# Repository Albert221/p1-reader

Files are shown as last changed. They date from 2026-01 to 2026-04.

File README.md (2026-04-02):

# P1 Reader

A simple device connecting a [Seeed ESP32-C3](https://wiki.seeedstudio.com/XIAO_ESP32C3_Getting_Started/) to a P1 port of the electricity meter. Based on ESPHome.

> [!NOTE]
> This project is dedicated to working with Polish STOEN operator, using GAMA 350 meter.

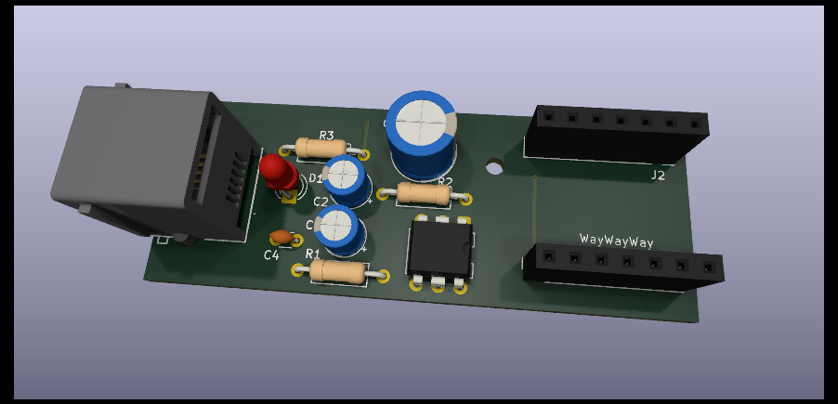
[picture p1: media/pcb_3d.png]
PCB 3D screenshot


## KiCAD

In `kicad/MJ3235-66-0` directory you should put a 3D model of the RJ12 connector that you can get from [here](https://www.tme.eu/pl/details/mj3235-66-0/zlacza-rj/gct/). I'm not sharing it as its license doesn't allow model file redistribution.

In PCB, there is 1K pull-up resistor between Data and 3V3 missing.

## Components

- [RJ12 connector](https://www.tme.eu/pl/details/mj3235-66-0/zlacza-rj/gct/)
- Electrolytic capacitors 100uF, 10uF, 1uF
- Ceramic capacitor 100nF
- Resistors 56Ω, 100Ω, 200Ω, 1kΩ
- Amber LED 3mm
- Optocoupler 4N35
- 2x 1x7 header socket (for connecting to ESP, chip facing down, USB to the edge of PCB)

## Sources

- https://forum.arturhome.pl/t/elgama-gama-350-i-port-p1/13722/21
- https://esphome.io/components/sensor/dsmr/
- https://www.netbeheernederland.nl/sites/default/files/2024-02/dsmr_5.0.2_p1_companion_standard.pdf ([Web Archive](https://web.archive.org/web/20260104071119/https://www.netbeheernederland.nl/sites/default/files/2024-02/dsmr_5.0.2_p1_companion_standard.pdf))

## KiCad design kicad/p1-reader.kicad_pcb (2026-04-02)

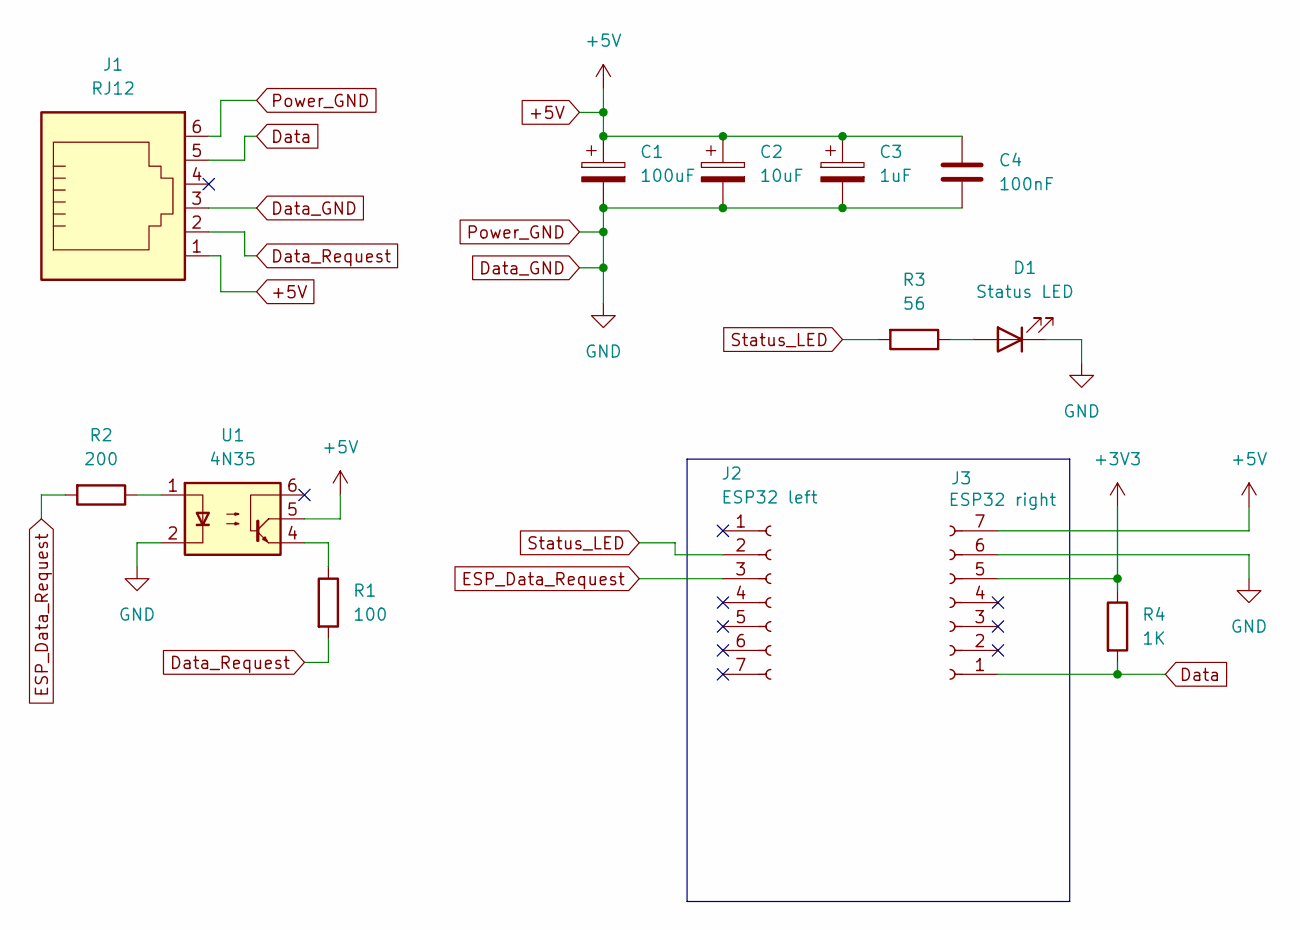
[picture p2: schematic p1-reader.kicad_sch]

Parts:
C1: 100uF; CP_Radial_D8.0mm_P3.50mm
C2: 10uF; CP_Radial_D5.0mm_P2.00mm
C3: 1uF; CP_Radial_D5.0mm_P2.50mm
C4: 100nF; C_Disc_D3.0mm_W1.6mm_P2.50mm
D1: Status LED; LED_D3.0mm
J1: RJ12; MJ3235660
J2: ESP32 left; PinSocket_1x07_P2.54mm_Vertical
J3: ESP32 right; PinSocket_1x07_P2.54mm_Vertical
R1: 100; R_Axial_DIN0207_L6.3mm_D2.5mm_P10.16mm_Horizontal
R2: 200; R_Axial_DIN0207_L6.3mm_D2.5mm_P10.16mm_Horizontal
R3: 56; R_Axial_DIN0207_L6.3mm_D2.5mm_P10.16mm_Horizontal
R4: 1K
U1: 4N35; DIP-6_W7.62mm

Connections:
+3V3: J3.5, R4.1
+5V: C1.1, C2.1, C3.1, C4.1, J1.1, J3.7, U1.5
Data: J1.5, J3.1, R4.2
Data_GND: C1.2, C2.2, C3.2, C4.2, D1.1 (K), J1.3, J1.6, J3.6, U1.2
Data_Request: J1.2, R1.2
ESP_Data_Request: J2.3, R2.2
unnamed: D1.2 (A), R3.1
unnamed: R1.1, U1.4
unnamed: R2.1, U1.1
Status_LED: J2.2, R3.2

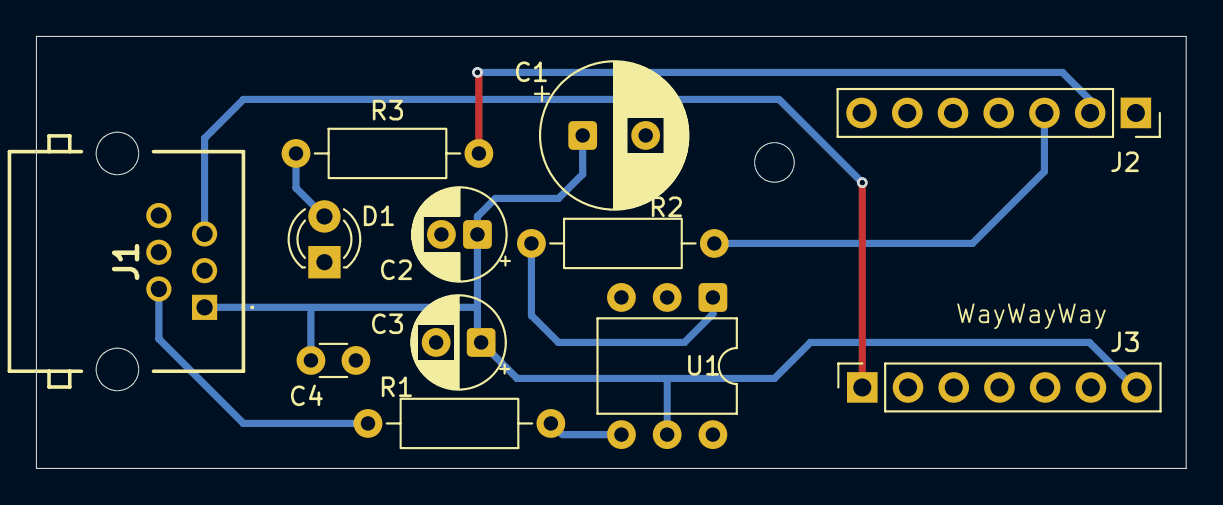
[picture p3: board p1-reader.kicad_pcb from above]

Board: 2 copper layers, 63.9 x 24.0 mm, 12 parts (0 on the bottom side), 9 nets.

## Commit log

2026-01-06 Add status LED
    [p1-reader.kicad_pcb, p1-reader.kicad_sch]
2026-01-10 Change ESP32 framework type to Arduino
2026-04-02 Update for Stoen
    [p1-reader.kicad_pcb, p1-reader.kicad_sch]
